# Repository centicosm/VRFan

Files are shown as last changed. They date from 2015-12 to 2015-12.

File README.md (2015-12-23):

# VRFan
VRFan consists of firmware, schematic, and PCB for an adapter used to convert a standard 'dumb' USB fan into a HID device, with the intention of doing something with the USB port available on the Oculus Rift DevKit 2 HMD.
As a HID device, the fan is software controllable and can be turned on or off at times appropriate for a particular VR scene.

Programs to test device functionality for both windows (in C#) and Linux (in C) are in the WindowsApp and VRFan_LinuxTester directories respectively.

The device is powered over USB and utilizes a PIC16F1455 as the controller and MPLab/XC8 as the toolchain.  Schematic and PCB are in KiCad.

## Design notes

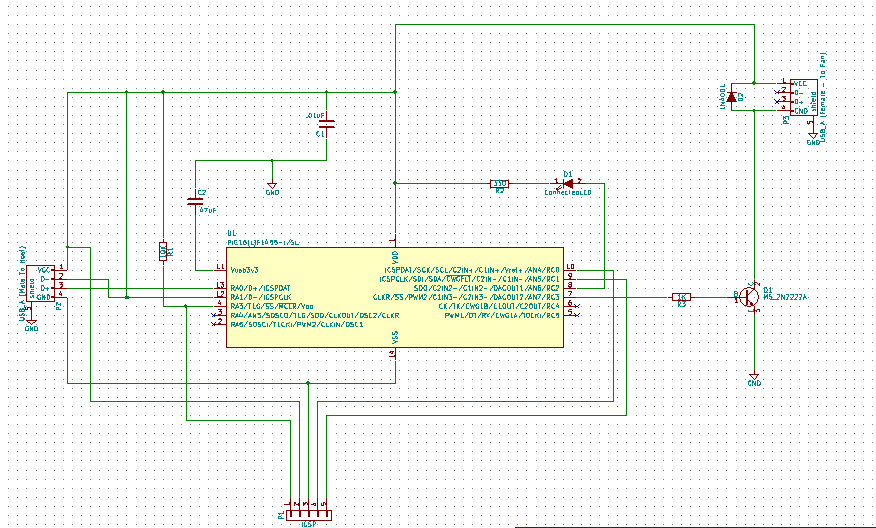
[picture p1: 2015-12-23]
images/Schematic.png

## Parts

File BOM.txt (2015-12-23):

PIC16f1455 SOIC
330 1/4W Resistor
1K 1/4W Resistor
10K 1/4W Resistor
USB-A Male header
USB-A Male header
5-pin .1 Header for ICSP (optional)
2n222A 
3mm LED
1N4001 Diode
.47uF Capacitor
.01uF Capacitor

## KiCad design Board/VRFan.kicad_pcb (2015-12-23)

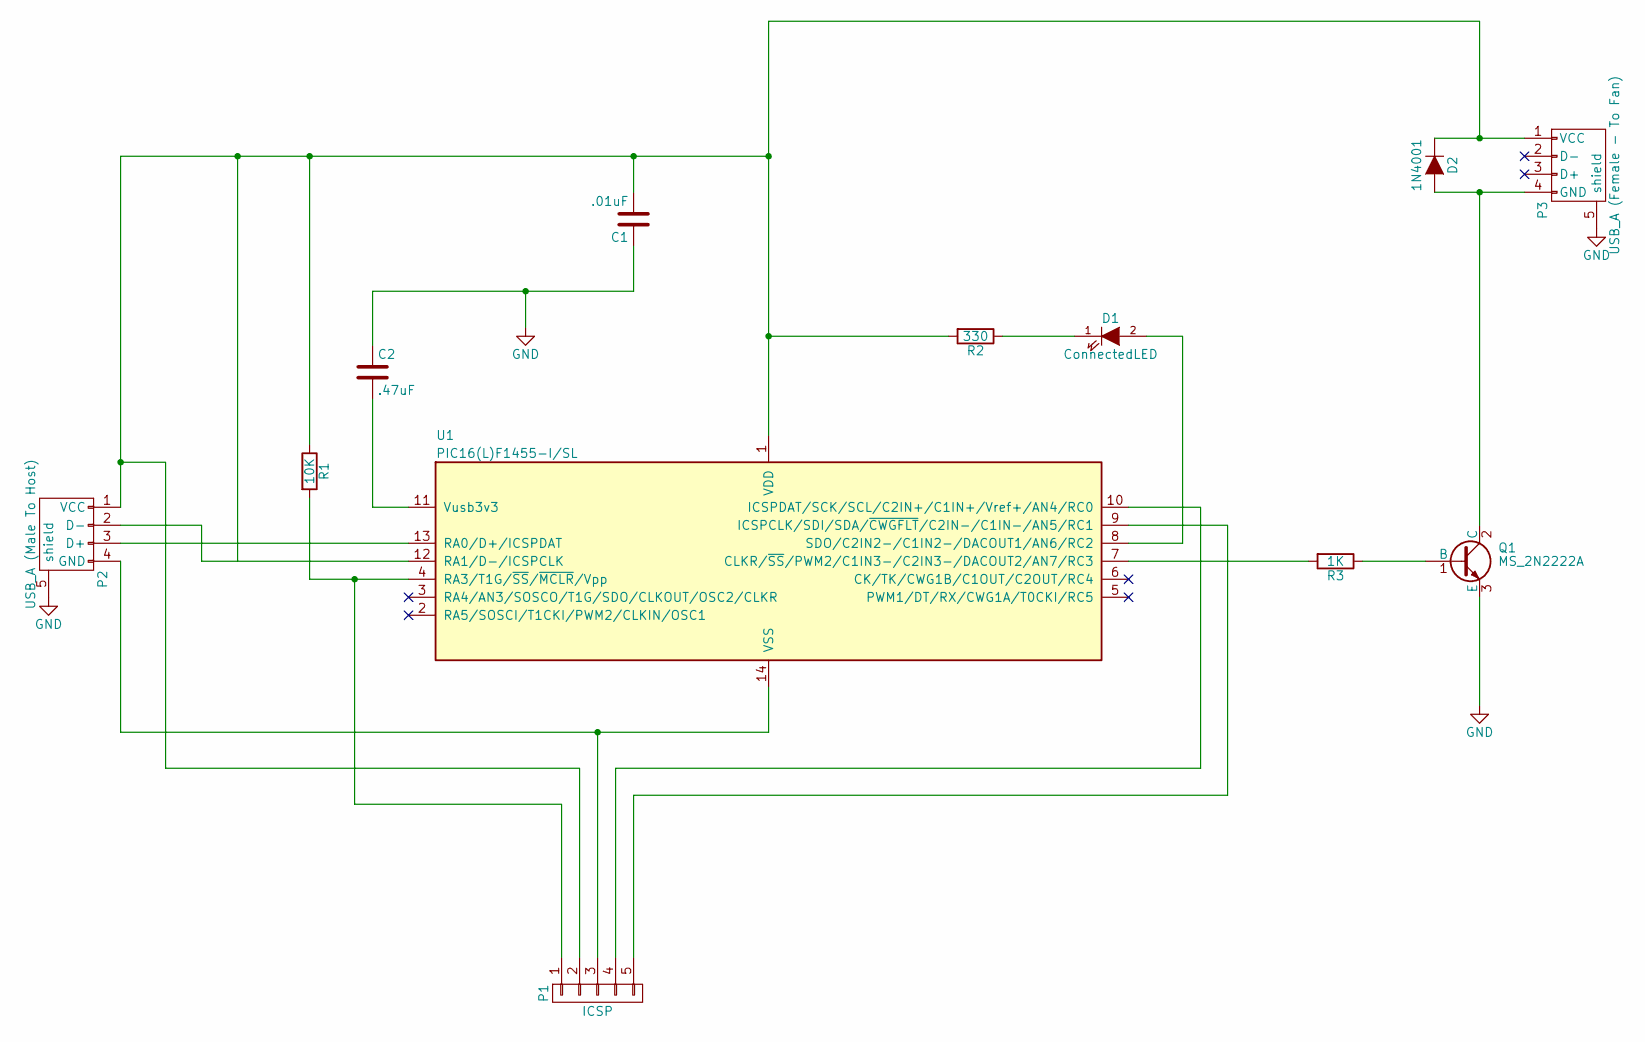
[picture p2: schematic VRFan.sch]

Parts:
C1: .01uF; C_Disc_D7.5_P5
C2: .47uF; C_Disc_D6_P5
D1: ConnectedLED; LED-3MM
D2: 1N4001; Diode_DO-41_SOD81_Horizontal_RM10
P1: ICSP; Pin_Header_Angled_1x05
P2: USB_A (Male To Host); Pin_Header_Angled_1x05
P3: USB_A (Female - To Fan); USB_A
Q1: MS_2N2222A
R1: 10K; Resistor_Horizontal_RM10mm
R2: 330; Resistor_Horizontal_RM10mm
R3: 1K; Resistor_Horizontal_RM10mm
U1: PIC16(L)F1455-I/SL

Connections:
GND: C1.1, C2.1, P2.5 (shield), P3.5 (shield), Q1.3 (E)
unnamed: C1.2, D2.1 (K), P1.2, P2.1 (VCC), P3.1 (VCC), R1.1, R2.2, U1.1 (VDD)
unnamed: C2.2, U1.11 (Vusb3v3)
unnamed: D1.1 (K), R2.1
unnamed: D1.2 (A), U1.8 (SDO/C2IN2-/C1IN2-/DACOUT1/AN6/RC2)
unnamed: D2.2 (A), P3.4 (GND), Q1.2 (C)
unnamed: P1.1, R1.2, U1.4 (RA3/T1G/~SS~/~MCLR~/Vpp)
unnamed: P1.3, P2.4 (GND), U1.14 (VSS)
unnamed: P1.4, U1.10 (ICSPDAT/SCK/SCL/C2IN+/C1IN+/Vref+/AN4/R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)
unnamed: P1.5, U1.9 (ICSPCLK/SDI/SDA/~CWGFLT~/C2IN-/C1IN-/AN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)
unnamed: P2.2 (D-), U1.12 (RA1/D-/ICSPCLK)
unnamed: P2.3 (D+), U1.13 (RA0/D+/ICSPDAT)
unnamed: Q1.1 (B), R3.1
unnamed: R3.2, U1.7 (CLKR/~SS~/PWM2/C1IN3-/C2IN3-/DACOUT2/AN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)

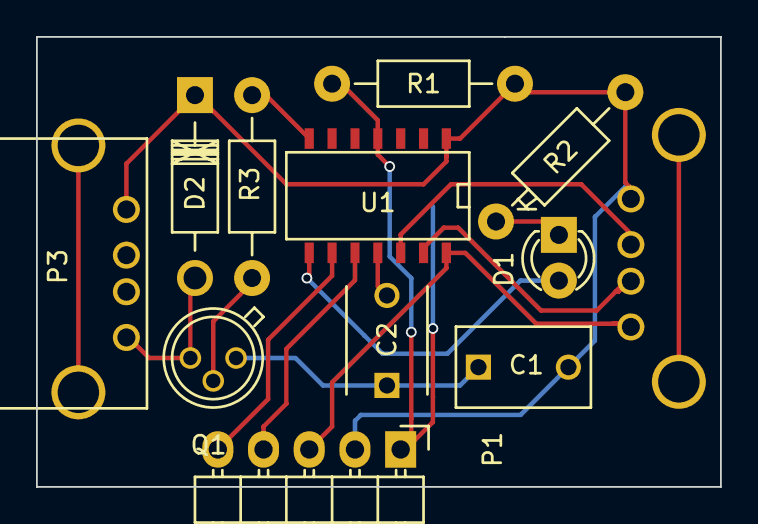
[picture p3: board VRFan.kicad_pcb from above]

Board: 2 copper layers, 38.0 x 25.0 mm, 12 parts (1 on the bottom side), 14 nets.

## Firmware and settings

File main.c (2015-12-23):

#include "system.h"
#include <usb/usb_device_hid.h>
#include "vrfan_app.h"
#include "mcc_generated_files/mcc.h"
#include "usb_config.h"
#include "vrfan_app.h"
#include <usb/usb.h>


// the only interrupt we are working with is USB related
void interrupt Handle_Interrupt() {
    USBDeviceTasks();
} 
    



void main(void) {
    
   SYSTEM_Initialize();

   // The led is used to inidicate USB connection status,  if off, the usb connection
   //    has been initialized, otherwise it will stay on to indicate an error
   LEDPIN_SetLow();
   
   USBDeviceInit();
   USBDeviceAttach();
   
    while(true) {
            
        // wait until usb is configured to do anything
        if( USBGetDeviceState() >= CONFIGURED_STATE ){
            Run_VRFan();
        }
    }
}


// The main USB event handler
bool USER_USB_CALLBACK_EVENT_HANDLER(USB_EVENT event, void *pdata, uint16_t size) {
    
    switch(event) {
 
        case EVENT_CONFIGURED:
            Init_HIDDevice();
            break;

            
        case EVENT_EP0_REQUEST:
            USBCheckHIDRequest();
            break;


        default:
            break;
    }
    return true;
}

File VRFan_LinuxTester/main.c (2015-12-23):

#include <stdlib.h>
#include <stdio.h>
#include <sys/ioctl.h>
#include <sys/types.h>
#include <sys/stat.h>
#include <asm/types.h>
#include <fcntl.h>
#include <unistd.h>
#include <linux/hiddev.h>
#include <linux/input.h>


#define VRFAN_FAN_OFF   0x30
#define VRFAN_FAN_ON    0x31
#define VRFAN_LED_OFF   0x40
#define VRFAN_LED_ON    0x41


int main(int argc, char **argv) {


	if (argc != 2) {
		printf("\n\nUsage: VRFanTester /path/to/hid/device\n\n");
		exit(1);
	}


	int fd = -1;
	fd = open(argv[1], O_RDONLY );
	if (fd < 0) {
		printf("Could not open: %s, make sure the device exists and you have the appropriate permissions\n", argv[1]);
		printf("You can find the device name by running: 'dmesg | grep VRFan' and look for 'hiddevX in the output\n");
		exit(1);
	}


	bool done = false;

	int cmd = 0;
	unsigned char cmdByte = 0x00;
	while (!done) {
		printf("\n");
		printf("\t1 - Turn LED on\n");
		printf("\t2 - Turn LED off\n");
		printf("\t3 - Turn Fan on\n");
		printf("\t4 - Turn Fan off\n");
		printf("\t5 - Exit\n");

		scanf("%d", &cmd);

		cmdByte = 0;
		if (cmd == 5) {
			done = true;
		}
		else if (cmd == 1) {
			cmdByte = VRFAN_LED_ON;
		}
		else if (cmd == 2) {
			cmdByte = VRFAN_LED_OFF;
		}
		else if (cmd == 3) {
			cmdByte = VRFAN_FAN_ON;
		}
		else if (cmd == 4) {
			cmdByte = VRFAN_FAN_OFF;
		}
		if (cmdByte != 0) {
		
			int n = 64;
        		struct hiddev_report_info rep_info_i, rep_info_u;
        		struct hiddev_usage_ref_multi ref_multi_i, ref_multi_u;
        		
			rep_info_u.report_type = HID_REPORT_TYPE_OUTPUT;
        		rep_info_i.report_type = HID_REPORT_TYPE_INPUT;
        		rep_info_u.report_id = HID_REPORT_ID_FIRST;
			rep_info_i.report_id = HID_REPORT_ID_FIRST;
        		rep_info_u.num_fields = 1;
			rep_info_i.num_fields = 1;
        		ref_multi_u.uref.report_type = HID_REPORT_TYPE_OUTPUT;
        		ref_multi_i.uref.report_type = HID_REPORT_TYPE_INPUT;
        		ref_multi_u.uref.report_id = HID_REPORT_ID_FIRST;
			ref_multi_i.uref.report_id = HID_REPORT_ID_FIRST;
        		ref_multi_u.uref.field_index = 0;
			ref_multi_i.uref.field_index = 0;
        		ref_multi_u.uref.usage_index = 0;
			ref_multi_i.uref.usage_index = 0;
        		ref_multi_u.num_values = n;
			ref_multi_i.num_values = n;
 			
			for(int i = 0; i < n; i++) {
				ref_multi_u.values[i] = cmdByte;
			}

			ioctl(fd,HIDIOCSUSAGES, &ref_multi_u);
			ioctl(fd,HIDIOCSREPORT, &rep_info_u);
			ioctl(fd,HIDIOCGUSAGES, &ref_multi_i);
			ioctl(fd,HIDIOCGREPORT, &rep_info_i);
		}
	}

	close(fd);

	return 1;
}
